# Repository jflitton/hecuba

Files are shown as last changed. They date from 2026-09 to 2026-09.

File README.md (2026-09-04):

# Hecuba

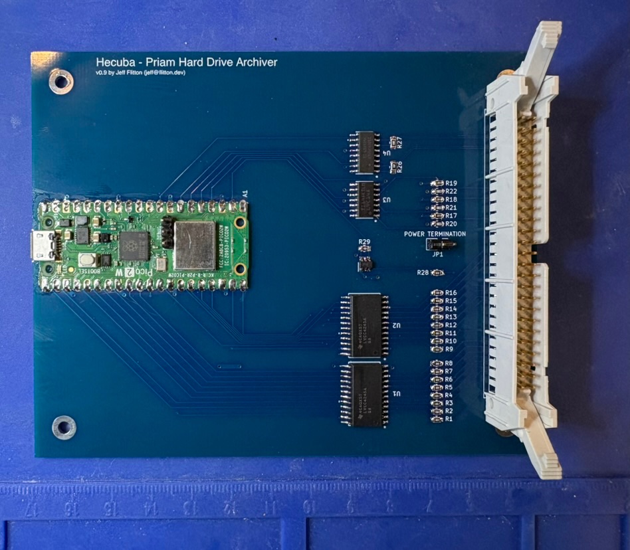
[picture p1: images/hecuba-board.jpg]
Hecuba interface board, rev 0.9, with the Pico 2 W fitted and the 50-pin drive connector on the right


A read-only imager for Priam DISKOS 8-inch Winchester drives, talking to the
drive over its native PRIAM 50-pin interface. Three parts: a small interface
board, firmware for the Raspberry Pi Pico 2 W that plugs into it, and host-side
Python tools that image the drive, recover damaged sectors offline, and walk
the recovered filesystem.

It was built to recover a Priam 3450 pulled from an Intel Multibus development
system (iSBC 215 controller, iRMX-86), and has imaged that drive in full. The
name: Hecuba was queen of Troy and wife of Priam.

## For data preservationists

If you have a Priam DISKOS 8-inch drive (a 3450, or likely a 7050) whose
contents you want to archive, email <jeff@flitton.dev>. I have a handful of
assembled Hecuba boards and can send you one. I am also glad to help with the
imaging and recovery, and to answer questions about the drive or its interface.

## Layout

| Directory | Contents | README |
|---|---|---|
| `hardware/` | KiCad project for the interface board: schematic, layout, BOM, measured termination values, 50-pin pinout | [hardware/README.md](hardware/README.md) |
| `firmware/` | Pico 2 W firmware: PRIAM register bus, PIO/DMA track capture, USB serial console | [firmware/README.md](firmware/README.md) |
| `software/` | Host tools: whole-drive imaging, three offline recovery passes, iSBC 215 sector decoder, iRMX-86 filesystem walker, defect map | [software/README.md](software/README.md) |

## Why it exists

These drives have a unique interface that resembles SASI at first glance but
is distinctly different.

- The heads move only on the drive's own command. There is no STEP line; a seek
  is a register write over the ribbon. The drive must be powered, spun up, and
  answering before it will read anything.
- The interface is recovered NRZ data plus clock on RS-422 pairs at 6.4 Mbit/s,
  not raw flux. A flux imager has nothing to read.

Acquisition and decoding are kept separate: capture each track once, cleanly,
then decode and repair offline, minimizing drive wear.

## Workflow

1. Build the board (`hardware/`). Rev 0.9A is fabricated and assembled.
2. Build and flash the firmware (`firmware/`), then bring the drive up from the
   USB serial console: `up`, `id`, `pins`, `stair`.
3. Image the drive with `software/sweep.py`, which drives that console and
   writes per-track sector images plus every raw capture.
4. Recover remaining sectors offline with `vote_repair.py`, `rescue.py`, and
   `deep_rescue.py`.
5. Walk the volume with `irmx_fs.py`, and attribute unrecovered sectors with
   `defect_map.py`.

## Read-only

The board has no copper on the write lines, and the firmware has no code path
that asserts WRITE GATE. Writing to a disk would require modifying the board.

## Scope

The sector decoder and filesystem walker target what this drive held: the Intel
iSBC 215 512-byte sector format and iRMX-86 named volumes. The board and
firmware are format-agnostic and capture raw bits from any drive with the PRIAM
interface. Termination values in `hardware/` were measured on one drive;
measure yours before populating.

Only the DISKOS 3450 has been tested. The DISKOS 7050 shares the same
interface, electrical spec, and service manual, so the board and firmware
should work on it as well, unconfirmed. The 7050 has 1049 cylinders to the
3450's 525, and that count is hardcoded in `firmware/include/priam_proto.h`
and `software/sweep.py`; the `id` command also expects the 3450's ID code.

No disk contents are part of this repository.

## License

The firmware and software are released under the MIT License, see
[LICENSE](LICENSE). The hardware design under `hardware/` is released under the
CERN Open Hardware Licence Version 2, Permissive (CERN-OHL-P-2.0), see
[hardware/LICENSE](hardware/LICENSE).

Both licenses allow commercial use, and both require that the copyright notice
and license text stay with copies and derived works. Both disclaim all
warranties: the software, the firmware, the design files, and any board built
from them are provided as is, and the risk of building and using them is
yours. Vendor symbol and footprint files under `hardware/lib/` are Texas
Instruments' and are not covered by either license.

## Reference documents

- [Priam 8-inch Winchester maintenance manual, July 1982](https://bitsavers.org/pdf/priam/Priam8_Maint_Jul82.pdf),
  and its [drawings volume](https://bitsavers.org/pdf/priam/Priam8_Maint_Drawings_Jul82.pdf)
  (schematics; an [800 dpi scan](https://bitsavers.org/pdf/priam/Priam8_Maint_Drawings_800dpi_Jul82.pdf) is also there)
- [Intel iSBC 215 Winchester Disk Controller Hardware Reference Manual,
  121593-002, September 1981](https://bitsavers.org/pdf/intel/iSBC/121593-002_iSBC_215_Winchester_Disk_Controller_Hardware_Reference_Manual_Sep1981.pdf)
- David Gesswein's excellent [mfm](https://www.pdp8online.com/mfm/) project, which documents the iSBC 215 sector format

## Author

Jeff Flitton, <jeff@flitton.dev>

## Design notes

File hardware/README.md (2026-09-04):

# Hecuba hardware

KiCad project for the Hecuba interface board. It sits between a Priam DISKOS
8-inch Winchester drive's native 50-pin interface and a Raspberry Pi Pico 2 W
(ref `A1`), which runs the firmware in `../firmware`. Rev 0.9A is fabricated,
assembled, and has imaged a full Priam 3450. Read-only by design.

## Why a custom board

The Priam 3450 (about 35 MB, 3,600 RPM, 5 heads, 525 cylinders) fits none of
the usual readers.

- No STEP line. Heads are positioned by a closed-loop voice-coil servo under an
  on-board 8035. A seek is a register write plus a Seek command, and the drive
  must be powered, spun up, and taking commands before it returns a bit.
- Not a flux interface. The drive does its own data separation and outputs
  recovered NRZ data plus clock on RS-422 pairs at 6.4 Mbit/s.
- The sector format belongs to the controller that wrote the disk (an Intel
  iSBC 215 here), not to the drive. Decoding happens offline in `../software`.
- Not SASI, despite the 50-pin ribbon and 8-bit active-low bus. PRIAM has no
  REQ/ACK handshake and carries read data on separate differential pairs.

## Building one

| | |
|---|---|
| Board | 2 layers, 125 x 104 mm, 1.6 mm. Signals on top; bottom is a ground pour with +5 V and +3.3 V routed through it as 1 mm paths |
| Tracks and vias | 0.2 mm signal, 1.0 mm power. Vias 0.6 mm / 0.3 mm hole (1.0 / 0.6 on power) |
| Smallest features | 0.2 mm track, 0.3 mm hole, 0.5 mm copper to edge |
| Packages | SOIC and SOT-23-6 ICs, 0805 passives. Hand-solderable in about an hour |
| Mounting | Four 3 mm plated holes, grounded |
| Parts list | `bom/bom.csv`, with a column for parts deliberately left unpopulated |
| Placement guide | `bom/ibom.html`, interactive; click a part to see where it goes |

All ICs are current-production TI parts as of 2026. Gerbers are plotted from
KiCad when needed and are not committed.

Routing rules for a respin:

- Only READ DATA and READ/REF CLOCK need care. Route each as a tight parallel
  pair over unbroken ground, and keep the two pairs apart. No impedance control
  and no length matching (the skew budget at 6.4 Mbit/s is about 170 mm).
- Everything else is slow. Keep the 8 data-bus lines grouped.
- Damping resistors at the source, termination at the receiver, and each
  100 nF capacitor hard against its power pin with its own ground via.

## Parts

| Ref | Part | Function | Datasheet |
|---|---|---|---|
| A1 | Pico 2 W (RP2350) | Controller. Powers the board over USB | [raspberrypi.com](https://datasheets.raspberrypi.com/picow/pico-2-w-datasheet.pdf) |
| U1 | SN74LVC4245A | 8-bit data bus, bidirectional. Direction set by the Pico (GP8) | [ti.com](https://www.ti.com/lit/ds/symlink/sn74lvc4245a.pdf) |
| U2 | SN74LVC4245A | Outbound control lines: address, strobes, head select, read gate. Direction strapped | [ti.com](https://www.ti.com/lit/ds/symlink/sn74lvc4245a.pdf) |
| U3 | SN74LVC14A | Schmitt-trigger inverters on INDEX, READY, SECTOR MARK | [ti.com](https://www.ti.com/lit/ds/symlink/sn74lvc14a.pdf) |
| U4 | AM26LV32E | RS-422 receivers for READ DATA and READ/REF CLOCK. Receive only | [ti.com](https://www.ti.com/lit/ds/symlink/am26lv32e.pdf) |
| U5 | SN74LVC1T45 | -RESET driver. Direction strapped | [ti.com](https://www.ti.com/lit/ds/symlink/sn74lvc1t45.pdf) |
| J1 | 2x25 IDC header | 50-pin ribbon to the drive | |

## Termination

Measured on one drive. Measure yours before populating. The manual's generic
values assume the controller terminates everything; this drive terminates most
of the bus internally. Values were measured at the connector with the drive
unpowered and the ribbon off.

| Part | Value | Fitted | Reason |
|---|---|---|---|
| R1-R16, R28 | 0 ohm | yes | Series damping on outbound lines. The drive terminates this bus at about 179 ohm; even 33 ohm in series lifts a logic low to about 0.72 V against a 0.8 V threshold. Fit 10 ohm or less only if a scope shows overshoot |
| R17 / R20 | 220 / 330 ohm | yes | INDEX pull-up and pull-down. INDEX measured open at the drive. Settles near 3.0 V released |
| R18-R19 / R21-R22 | 220 / 330 ohm | no | READY and SECTOR MARK are pulled up inside the drive (130 / 175 ohm measured). Fit only if J1 pin 28 is left unpowered |
| R26 | 1 k | yes | Bias across the CLOCK pair, which measured 95 ohm. 100 ohm here would load the pair to 49 ohm |
| R27 | 100 ohm | yes | Termination across the DATA pair, which measured 252 ohm |
| R29 | 10 k | yes | Pull-up on GP17 (-RESET). Holds reset deasserted through boot |
| C1-C8 | 100 nF | yes | Decoupling, one per power pin |
| C9 / C10 | 10 uF | yes | Bulk on each rail at the Pico's power pins |
| JP1 | 2-pin header | shunt open | +5 V to J1 pin 28 (terminator power). Not needed on the drive tested |

## 50-pin connector (J1)

| Signal | Pin | Direction | Connects to |
|---|---|---|---|
| DBUS 0-7 | 2-9 | both | U1 via R1-R8 |
| -READ GATE | 11 | to drive | U2 via R9 |
| -RESET | 13 | to drive | U5 via R28 |
| -WRITE GATE | 15 | to drive | not connected |
| -RD / -WR | 17 / 18 | to drive | U2 via R10 / R11 |
| +AD 1 / +AD 0 | 19 / 20 | to drive | U2 via R12 / R13 |
| -DRIVE SELECT 1 | 22 | to drive | ground (always selected) |
| -DRIVE SELECT 2-4 | 23-25 | to drive | not connected |
| +5 V to terminator | 28 | power | JP1 (open) |
| -HEAD SELECT 4 / 2 / 1 | 29 / 30 / 31 | to drive | U2 via R14 / R15 / R16 |
| -INDEX | 33 | from drive | U3, with R17 / R20 |
| -READY | 35 | from drive | U3 |
| -SECTOR MARK | 37 | from drive | U3 |
| WRITE DATA pair | 39 / 40 | to drive | not connected |
| WRITE CLOCK pair | 42 / 43 | to drive | not connected |
| READ/REF CLOCK pair | 45 / 46 | from drive | U4, R26 across |
| READ DATA pair | 48 / 49 | from drive | U4, R27 across |

Ground pins 1, 10, 12, 14, 16, 21, 26, 27, 32, 34, 36, 38, 41, 44, 47, 50
connect to the ground plane.

## Power

- Drive rails (+24 V, +5 V, -5 V, -12 V, about 100 W total) come from a bench
  supply into the drive's own connector. The board neither carries nor senses
  them. Current-limit and watch +24 V at power-up; it runs the spindle and the
  voice coil.
- Board rails come from the Pico's USB. VBUS (pin 40) feeds the drive-facing
  side of the translators and the status pull-ups. The Pico's 3.3 V regulator
  (pin 36) feeds the Pico-facing side.
- Board draw is about 250 mA idle and 400 to 600 mA peak (the radio spikes on
  transmit). Use a 1.5 A supply or powered hub.

Power the Pico first, then the drive, and do not replug USB while the drive is
powered. Until firmware init runs, the Pico's pins are inputs with pull-downs,
which asserts every active-low control line through U2. Only -RESET is
protected in hardware (R29).

## Noteworthy facts

- **Write lines have no copper.** WRITE GATE, WRITE DATA, and WRITE CLOCK
  appear on the connector symbol only. No trace, no resistor. Writing would
  require adding wires to the board. The drive's own Write Enable switch is
  also off, and its internal terminator holds WRITE GATE deasserted.
- **The drive is 5 V TTL; the RP2350 is 3.3 V and not 5 V tolerant.** Every
  signal crosses a translator. Net names carry the level: `DBUS0` on the drive
  side, `DBUS0_3V3` on the Pico side.
- **Status lines invert.** U3 inverts, so INDEX, READY, and SECTOR MARK read
  active-high at the Pico while every other PRIAM signal is active-low. The
  schematic writes active-low nets as `~{NAME}`; the drive manual uses a
  leading minus. The full per-line chain is in
  `../firmware/include/board_pins.h`.
- **U3 is a Schmitt trigger on purpose.** The drive's status outputs are
  open-collector 75462s with slow RC rising edges. Hysteresis turns each into
  one clean transition. The drive's own end uses 74LS14s for the same reason.
- **U4 is the E variant on purpose.** AM26LV32E adds hysteresis and an
  open-input fail-safe, so the read pairs hold a defined level before READ GATE
  asserts and before the drive's clock recovery locks.
- **R29 is load-bearing.** U5 has no output enable and follows GP17 from
  power-on, and the RP2350 boots GP17 as an input with a pull-down. Without
  R29 every power-up would reset the drive.
- **DRIVE SELECT 1 is tied to ground.** One drive, permanently selected, no
  chip-select GPIO. The data bus still only drives back during a read strobe.
- **Unused U3 and U4 inputs are tied off.** Floating Schmitt or differential
  inputs oscillate.
- **R26 and R27 differ by 10x** for two pairs on the same connector. Only
  measurement finds that.

## Files

| Path | Contents |
|---|---|
| `hecuba.kicad_pro` | Project settings, net classes, design rules |
| `hecuba.kicad_sch` | Schematic, one sheet |
| `hecuba.kicad_pcb` | Board layout |
| `hecuba.kicad_prl` | KiCad UI state |
| `hecuba.kicad_sym` | Five project symbols. `PRIAM_50` is the drive connector with real PRIAM signal names |
| `footprints.pretty/` | Footprints for the four ICs, registered by `fp-lib-table` so the project opens standalone |
| `fp-lib-table` | Points KiCad at the folder above |
| `lib/<PART>/` | Vendor symbol and footprint downloads per chip, untouched. Datasheets are linked from the parts table, not stored here |
| `bom/bom.csv` | Parts list with populate / do-not-populate column |
| `bom/ibom.html` | Interactive BOM |

`.gitignore` covers KiCad backups and netlist output.

## License

CERN Open Hardware Licence Version 2, Permissive (CERN-OHL-P-2.0). The full
text is in [LICENSE](LICENSE). Keep the copyright and license notices with any
copy or derivative of the design files, and on boards where practicable (the
silkscreen already carries the author line). The design is provided as is, with
no warranty, and the risk of building and using a board from it is yours.

Files under `lib/<PART>/` are Texas Instruments vendor downloads under TI's own
terms and are not covered by this license.

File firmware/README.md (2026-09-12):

# Hecuba firmware

Firmware for the Raspberry Pi Pico 2 W (RP2350) on the Hecuba board (ref `A1` in
`../hardware`). It drives a Priam DISKOS 8-inch drive over its native 50-pin
interface and captures whole-track NRZ bit streams for offload over USB serial.

Read-only. No code path asserts -WRITE GATE or drives WRITE DATA / WRITE CLOCK,
and the board has no copper on those pins.

## Build and flash

VS Code: install the official Raspberry Pi Pico extension and open `firmware/`
as the project root (the extension only handles single-folder workspaces). It
supplies the SDK, CMake, Ninja, the ARM toolchain, picotool, and OpenOCD.

Command line:

```bash
export PICO_SDK_PATH=/path/to/pico-sdk          # 2.1 or newer
cmake -B build -G Ninja \
  -DPICO_TOOLCHAIN_PATH=/path/to/arm-gnu-toolchain \
  -DCMAKE_PREFIX_PATH="$(brew --prefix)"        # locates picotool
cmake --build build                             # build/hecuba.uf2
```

Flash: hold BOOTSEL while plugging in USB, then drag `build/hecuba.uf2` onto the
`RP2350` drive or run `picotool load -fx build/hecuba.uf2`.

- Pico SDK 2.1 is the minimum. Older SDKs do not know the RP2350.
- Use Arm's own `arm-none-eabi` toolchain. Homebrew's formula lacks newlib and
  fails at link with `cannot read spec file 'nosys.specs'`.

## Console

All control and diagnostics go over USB serial at 115200. There is no debug
UART (GP0 and GP1 are data bus lines). The banner reprints on every connect.
Type `help`.

```bash
screen /dev/tty.usbmodem* 115200
```

| Command | Action |
|---|---|
| `status` | Read and decode the Status register |
| `up [secs]` | Sequence Up: spin up, restore to cylinder 0, wait for READY. About 30 s; timeout default 35 |
| `down` | Sequence Down: park heads, brake spindle |
| `seek <cyl>` | Seek to cylinder 0 to 524 |
| `head <0-4>` | Select a data head |
| `gate on\|off` | Assert or deassert -READ GATE |
| `id` | Read Drive ID. A 3450 returns `0x04` |
| `capture <cyl> <head>` | Seek, select head, open gate, settle, capture one INDEX-aligned track |
| `capraw [head]` | Capture with no seek and no status checks (bench and loopback) |
| `dump [n]` | Hexdump the first n words of the last capture (default 16) |
| `dumpb64 [n]` | Base64 the capture buffer to the host |
| `pins` | GPIO levels plus rising-edge counts over 100 ms |
| `reg r <ad>` | Raw register read (ad = 0, 1, 2) |
| `reg w <ad> <hex>` | Raw register write |
| `stair` | Seek staircase 0, 1, 0, 2, ... 524 with address readback at every step. About 1,050 seeks, a few minutes, any key aborts |
| `gating [off\|mark\|both] [drop_us] [data_off_us] [data_drop_us]` | Per-field -READ GATE pulses during capture. See below |
| `reset` | Pulse -RESET for 1 ms. Not part of any normal sequence |

Typical session:

```
> id
drive id = 0x04 (expect 0x04 for 3450)
> up
sequence up: OK  status 0x0B [READY SEEKCMP CYL0 ]
> pins
levels : INDEX=0 READY=1 SECTOR=0 CLK=1 DATA=0
edges/100ms: INDEX=6 SECTOR=138 (expect 6 / 138 spinning) CLK~... DATA~... (aliased; nonzero = alive)
> capture 0 0
(capture engine started on core1)
capture cyl 0 head 0: OK: 3780 words (15120 bytes)
> dumpb64
-----BEGIN CAPTURE b64 (3780 words, LE, first bit = LSB)-----
...
> down
sequence down: OK  status 0x00 []
```

`../software/sweep.py` drives this console to image a whole drive.

## Bench procedure

1. Power the Pico over USB first and let it boot. Do not replug USB while the
   drive is powered. Until `priam_bus_init()` runs, the Pico's pins are inputs
   with pull-downs, which asserts every active-low control line at once. Only
   -RESET is protected in hardware (R29).
2. Bring up the drive rails.
3. `up`, then `id`, then `pins`. A spinning drive shows about 6 INDEX and 138
   SECTOR MARK edges per 100 ms with READY=1. Clock and data counts are
   aliased; only nonzero matters.
4. Run `stair` before a long imaging run. It exercises the servo over its full
   travel and confirms the cylinder bit packing. It stops on the first failure.
5. Capture. `down` when finished.

Capture failures:

| Situation | Timeout | Message |
|---|---|---|
| No INDEX pulse | 60 ms | `FAIL: no INDEX edge, or clock never ran` |
| Clock stops mid-track | 250 ms | `PARTIAL: n/3780 words` |

Both point at `pins`. Zero clock edges with the drive spinning and the gate
open means the read channel is not reaching the board.

## Capture format

Raw sampled bits, no decoding. One capture is 3,780 32-bit words (15,120
bytes), about 12.5% more than one revolution (3,360 words, 13,440 bytes,
16.7 ms at 3,600 RPM). INDEX alignment is done in software, so the margin
guarantees a full INDEX-to-INDEX window with overlap rather than a gap.

- The first bit sampled is bit 0 of word 0, the 32nd is bit 31 (the PIO shifts
  right).
- `dumpb64` emits each word little-endian. The first bit off the platter is the
  LSB of the first byte received.

`../software/decode_scout.py` decodes this stream (iSBC 215 format, 512 B
sectors).

## Per-field gate re-sync

-READ GATE is pulsed off and on per field during a capture, following the
original controllers:

- PRIAM OEM/Service Manual 308000-0, Figure 3-40 and Table 3-15: READ GATE is
  asserted in the zero gap after SECTOR MARK and dropped before the next write
  splice. READ DATA is invalid for 9 µs after each assertion (PLO sync).
- iSBC 215 Hardware Reference Manual 121593-002, paragraphs 4-29 and 4-30:
  RD GATE is reset by END TIME at the end of the ID field's ECC and "again
  raised to search for the sync byte of the data field".

With the gate held across a write splice the separator's output for the
following field is unreliable and the field fails ECC.

Timing for the iSBC 215 sector format (1.24 µs per byte), from the SECTOR MARK
leading edge: ID sync byte about 22 µs, ID field end about 33 µs, data-field
write splice about 44 µs (the 215 writes ID fields and data fields in separate
format passes, so every sector has one), data sync byte about 68 µs.

```
gating                   show the setting (default: both 3 37 11)
gating both 3 37 11      gate off 3 µs at each SECTOR MARK, and off from 37 to
                         48 µs after it (spans the splice, ~18 µs of zeros left
                         for the resync)
gating mark [drop_us]    mark pulse only
gating off               gate held for the whole revolution
```

Capture lines report `[gating both, N drops, mark0 +NNus]`: N is the number of
gate pulses over the INDEX wait plus the track; `mark0` is the INDEX to first
SECTOR MARK time (spec 44.6 ± 1.4 µs).

## Noteworthy facts

- **Capture is PIO plus DMA, not CPU.** `src/capture.pio` is three
  instructions: wait for the drive's clock high, wait for it low, shift in one
  READ DATA bit. No local clock or sample rate exists; the drive's recovered
  clock paces everything. DMA drains the FIFO into RAM. A CPU breakpoint does
  not stop a capture.
- **Sample on the falling clock edge.** READ DATA changes shortly after the
  rising edge of READ/REF CLOCK, so a sample there lands on the transition.
  The falling edge is mid-cell.
- **Gate per field.** A capture with the gate held for the whole revolution
  loses the field after each write splice. See "Per-field gate re-sync".
- **Two cores by role.** core0 runs the register bus and USB console. core1
  runs only the capture engine and starts on the first capture, so a PIO or
  DMA problem cannot take the console down. The 1 Hz LED heartbeat stops during
  a capture because core0 blocks on core1.
- **pio1, not pio0.** The Pico 2 W LED hangs off the CYW43 radio, whose driver
  claims a pio0 state machine at startup. The wireless stack is linked only for
  the LED. There is no networking.
- **Status bits are invalid while BUSY is set.** SEEK COMPLETE, SEEK FAULT, and
  COMMAND REJECT flutter during spin-up. Wait for BUSY to clear before judging
  them. An early version aborted a good `up` with status `0xD0` for this reason.
- **DRIVE FAULT is never retried.** The firmware reports it and stops.
- **`down` can report FAIL with status `0x50` after a successful park.** The
  spindle brake outlasts the status timeout, leaving BUSY set.
- **`reset` on a sequenced-up drive restores it to cylinder 0** and takes
  about 450 ms to come back READY. DRIVE FAULT appears at once and the drive
  clears it itself; a fault that persists means the restore failed. A pulse
  of a few microseconds is enough, despite the manual's 100 ms figure.
- **Init order.** `priam_bus_init()` is the first call in `main()`. It writes
  each pin's idle level before switching it to output, because the SDK zeroes
  the output latch on init. The reverse order drives every active-low line low
  for a few microseconds.
- **Polarity.** Control outputs pass through a non-inverting buffer, so assert
  means drive the GPIO low. The three status inputs pass through an inverting
  Schmitt trigger and read active-high at the Pico. `include/board_pins.h`
  documents the chain for every line.
- **Geometry is the 3450's.** `include/priam_proto.h` fixes 525 cylinders and
  5 heads, and `seek`, `stair`, and `capture` reject cylinders above 524. A
  DISKOS 7050 (1049 cylinders, same interface) should work with those constants
  changed. Untested.

## Register interface

Three registers selected by AD0/AD1. Read and write address different
registers.

| Address | Write | Read |
|---|---|---|
| 0 | Command | Status |
| 1 | Target Address upper | Current Address upper |
| 2 | Target Address lower | Current Address lower |

Commands: `0x01` Sequence Up, `0x02` Sequence Down, `0x03` Restore, `0x04`
Seek, `0x05` Fault Reset, `0x10` Read Drive ID. A seek writes the cylinder into
registers 1 and 2, writes `0x04` to register 0, then polls register 0 until
BUSY clears.

Status bits: READY, SEEK COMPLETE, SEEK FAULT, CYLINDER ZERO, BUSY, DRIVE
FAULT, WRITE PROTECT, COMMAND REJECT. The console decodes them (`0x0B` prints
`[READY SEEKCMP CYL0 ]`).

Bus timing. There is no handshake beyond the strobes; every value is padded
above the manual's minimum using the SDK's minimum-cycle busy-wait.

| Parameter | Manual minimum | Used |
|---|---|---|
| Address setup before strobe | 60 ns | 80 ns |
| Data setup before -WR release | 60 ns | 80 ns |
| -WR low | 100 ns | 150 ns |
| -RD low | 100 ns | 150 ns |
| Data valid after -RD | 60 ns | 80 ns |
| Gap between strobes | 200 ns | 250 ns |

## Pin map

`include/board_pins.h` is authoritative.

| GPIO | Signal | Dir | Via | Notes |
|---|---|---|---|---|
| GP0-7 | DBUS 0-7 | both | U1 '4245 | Direction from GP8: 0 = Pico drives, 1 = drive drives |
| GP8 | DBUS direction | out | | Controls U1 |
| GP9, GP10 | AD0, AD1 | out | U2 '4245 | Register select, plain logic levels |
| GP11, GP12 | -RD, -WR | out | U2 | Strobes, assert = low |
| GP13-15 | -HEAD SELECT 1, 2, 4 | out | U2 | Assert = low. HS1 is bit 0, HS4 is bit 2 |
| GP16 | -READ GATE | out | U2 | Assert = low |
| GP17 | -RESET | out | U5 1T45 | Assert = low. R29 holds it deasserted through boot |
| GP18 | -INDEX | in | U3 '14, inverting | Reads active-high at the Pico |
| GP19 | -READY | in | U3, inverting | Reads active-high |
| GP20 | -SECTOR MARK | in | U3, inverting | Reads active-high |
| GP21 | READ/REF CLOCK | in | U4 RS-422 | The PIO `wait gpio` pin |
| GP22 | READ DATA | in | U4 RS-422 | The PIO `in pins` pin |

No drive-select GPIO. DRIVE SELECT 1 is tied asserted on the board.

## Debugging

No probe is needed. The drive was imaged using BOOTSEL flashing and the serial
console.

`.vscode/launch.json` is set up for a CMSIS-DAP probe (the Raspberry Pi Debug
Probe, or a Pico running `debugprobe_on_pico`: GP2 to SWCLK, GP3 to SWDIO,
ground to ground on the 3-pin debug header) with RTT logging. Enable RTT with
`pico_enable_stdio_rtt(hecuba 1)` in `CMakeLists.txt`; it keeps `printf` off
USB and away from the capture core. PIO and DMA keep running under a
breakpoint, so inspect captures with `dump` afterwards.

`c_cpp_properties.json` points IntelliSense at `build/compile_commands.json`,
which exists after the first configure. `settings.json` disables CMake Tools so
it does not fight the Pico extension.

## Files

| Path | Contents |
|---|---|
| `include/board_pins.h` | GPIO map with polarity and translator chain per line |
| `include/priam_proto.h` | Register addresses, command codes, Status bits, geometry, cylinder packing |
| `src/main.c` | Startup: park drive-facing lines, bring up USB and LED, run the console loop |
| `src/priam_bus.c`, `.h` | Register bus: strobes and timing through Sequence Up, Seek, head select |
| `src/capture.pio` | The three-instruction sampler |
| `src/capture.c`, `.h` | Capture engine on core1: PIO and DMA setup, INDEX alignment |
| `src/host_cli.c`, `.h` | The console |
| `CMakeLists.txt` | Selects the Pico 2 W, assembles the PIO program, links PIO, DMA, multicore, USB stdio |
| `pico_sdk_import.cmake` | Stock SDK locator, unmodified |
| `.vscode/` | Editor and debugger configuration |
| `build/` | Build output including `hecuba.uf2`. Generated, not committed |

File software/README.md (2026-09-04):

# Hecuba software

Host-side tools for the Hecuba board: image a Priam drive over the firmware's USB
console, recover more sectors offline from the saved raw captures, and walk the
iRMX-86 filesystem on the assembled image. Python 3. Only `sweep.py` needs an extra
package (pyserial).

Scripts in pipeline order:

## sweep.py

Whole-drive imaging. Drives the firmware console, captures each track, decodes it
inline, and re-reads until every sector validates or reads stop adding sectors.
Writes `image/manifest.json`, one `image/tracks/cylCCC_hN.bin` per track, and every
distinct raw capture under `image/raw/`. Resumable; reruns skip completed tracks.

    python3 sweep.py --probe                     # connect + status, no motion
    python3 sweep.py                             # image everything
    python3 sweep.py --cyls 0:100 --heads 1,2,3,4
    python3 sweep.py --revisit                   # retry previously-failed tracks

## vote_repair.py

Offline. For every sector still marked `failed`, extracts that sector's data field
from every saved raw capture, drops outlier reads, majority-votes per bit, and
ECC-checks the result. Writes winners back into `tracks/` and the manifest as `voted`.

    python3 vote_repair.py [--image image] [--min-reads 3] [--dry-run]

## rescue.py

Offline. Recovers sectors whose header is dead but whose data field is intact.
Builds a slot-to-sector map from header positions across all reads, then scans each
slot for an ECC-valid data field. Marks results `position`.

    python3 rescue.py [--image image] [--dry-run] [--jobs 8] [--cyls A:B]

## deep_rescue.py

Offline, last resort. Sliding ECC scan over the slot window, aligned per-bit vote
across reads, and single bit-slip repair. Marks results `deep`.

    python3 deep_rescue.py [--image image] [--dry-run] [--jobs 8]

## irmx_fs.py

Walks an iRMX-86 named volume: label, fnode table, directory tree. Reports per-file
intactness against a missing-sector list and writes the full listing to a file.

    python3 irmx_fs.py [--img volume.img] [--missing volume.missing.json] [--tree-out filetree.txt]

## defect_map.py

Decodes the Priam 3450 reserved area (cylinders 513 to 524) and the format-time
bad-track table on cylinder 523, then splits unrecovered sectors into factory
defects and real storage-era loss, attributed to owning files.

    python3 defect_map.py [--img volume.img] [--missing volume.missing.json] [--json defects.json]

## decode_scout.py

The iSBC 215 sector decoder every other script imports: header and data field
search at any bit alignment, CRC-32 ECC check, 4-bit burst correction. Also runs
standalone on a screen log or raw track files.

    python3 decode_scout.py <screenlog|track.bin>... [--out track.bin] [--peek]

## Notes

- `sweep.py`, `vote_repair.py`, `rescue.py`, and `deep_rescue.py` all write
  `image/manifest.json` and `image/tracks/`. Never run two of them at once.
- Sector states in the manifest: `valid`, `corrected` (burst-corrected on read),
  `voted`, `position`, `deep` (the three offline passes), `failed`, `no-header`,
  `erased-ff`.
- Images, raw captures, and anything recovered from a particular drive are not
  part of this repository.

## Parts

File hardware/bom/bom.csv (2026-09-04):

Ref | Qty | Value | Description | Manufacturer | MPN | Footprint | Populate | Notes
A1 | 1 | Pico 2 W | RP2350 controller module | Raspberry Pi | Pico 2 W (SC1634 - verify) | Pico 2 W module | Yes | Controller core (CORE-1); 3.3V GPIO not 5V tolerant
U1 | 1 | SN74LVC4245A | Octal 5V<->3.3V translating transceiver | Texas Instruments | SN74LVC4245ADWR | SOIC-24W | Yes | DBUS bidirectional; VCCA=5V VCCB=3.3V; DIR from GPIO
U2 | 1 | SN74LVC4245A | Octal 5V<->3.3V translating transceiver | Texas Instruments | SN74LVC4245ADWR | SOIC-24W | Yes | Control outputs; DIR strapped B->A (pin2=GND)
U3 | 1 | SN74LVC14A | Hex Schmitt-trigger inverter | Texas Instruments | SN74LVC14ADR | SOIC-14 | Yes | Status inputs (inverting -> active-high at core)
U4 | 1 | AM26LV32E | Quad RS-422 line receiver 3.3V | Texas Instruments | AM26LV32EIDR | SOIC-16 | Yes | READ DATA + READ/REF CLOCK; receiver-only
U5 | 1 | SN74LVC1T45 | Single-bit 5V<->3.3V translator | Texas Instruments | SN74LVC1T45DBVR | SOT-23-6 | Yes | Hardware -RESET driver (drive 8035 reset); VCCA=5V VCCB=3.3V; DIR(5)->GND (B->A)
J1 | 1 | 50-pin IDC | PRIAM 50-pin ribbon header 2x25 | Generic | TBD | IDC 2x25 2.54mm | Yes | To drive 50-pin connector
R1-R16 | 16 | 0R | Series source-damping (controller->drive) | Generic | TBD | 0805 | Yes | 0R default - keeping out an of an abundance of caution; <=10R if overshoot
R17 | 1 | 220R | Status pull-up to +5V (INDEX) | Generic | TBD | 0805 | Yes | INDEX terminator (with R20); drive open on INDEX (measured) so we terminate
R20 | 1 | 330R | Status pull-down to GND (INDEX) | Generic | TBD | 0805 | Yes | INDEX terminator (with R17)
R18-R19 | 2 | 220R | Status pull-up to +5V (READY/SECTOR) | Generic | TBD | 0805 | DNP | Drive pulls these up at term rail (measured) - populate only if J1 pin28 left unpowered
R21-R22 | 2 | 330R | Status pull-down to GND (READY/SECTOR) | Generic | TBD | 0805 | DNP | Pairs with R18-R19
R26 | 1 | 1k | RS-422 READ/REF CLOCK pair termination | Generic | TBD | 0805 | Yes | Drive terminates CLOCK pair (~95R measured) - light 1k bias; do NOT use 100R (->49R)
R27 | 1 | 100R | RS-422 READ DATA pair termination | Generic | TBD | 0805 | Yes | Drive weakly terminates DATA pair (252R measured) - supply ~100R
R28 | 1 | 0R | Series source-damping (-RESET to drive) | Generic | TBD | 0805 | Yes | U5 A-output (pin3) -> J1 pin13; 0R default (<=10R if overshoot)
R29 | 1 | 10k | GP17 pull-up to +3V3 | Generic | TBD | 0805 | Yes | Keeps -RESET deasserted through boot (U5 has no OE; RP2350 GP17 resets to input+pull-down)
C1-C8 | 8 | 100nF | X7R decoupling per Vcc pin | Kemet | C0805C104J5RACTU | 0805 | Yes | U1 x2; U2 x2; U3 x1; U4 x1; U5 x2
C9-C10 | 2 | 10uF | X7R bulk decoupling +5V and +3.3V | Murata | GRM21BZ71E106KE15K | 0805 | Yes
JP1 | 1 | 2-pin header | Terminator power select: +5V to J1 pin 28 | Generic | TBD | Header 1x2 2.54mm | Yes | Header populated; shunt OPEN by default - install only if drive needs host-supplied term power (verify; adds ~100mA to +5V)

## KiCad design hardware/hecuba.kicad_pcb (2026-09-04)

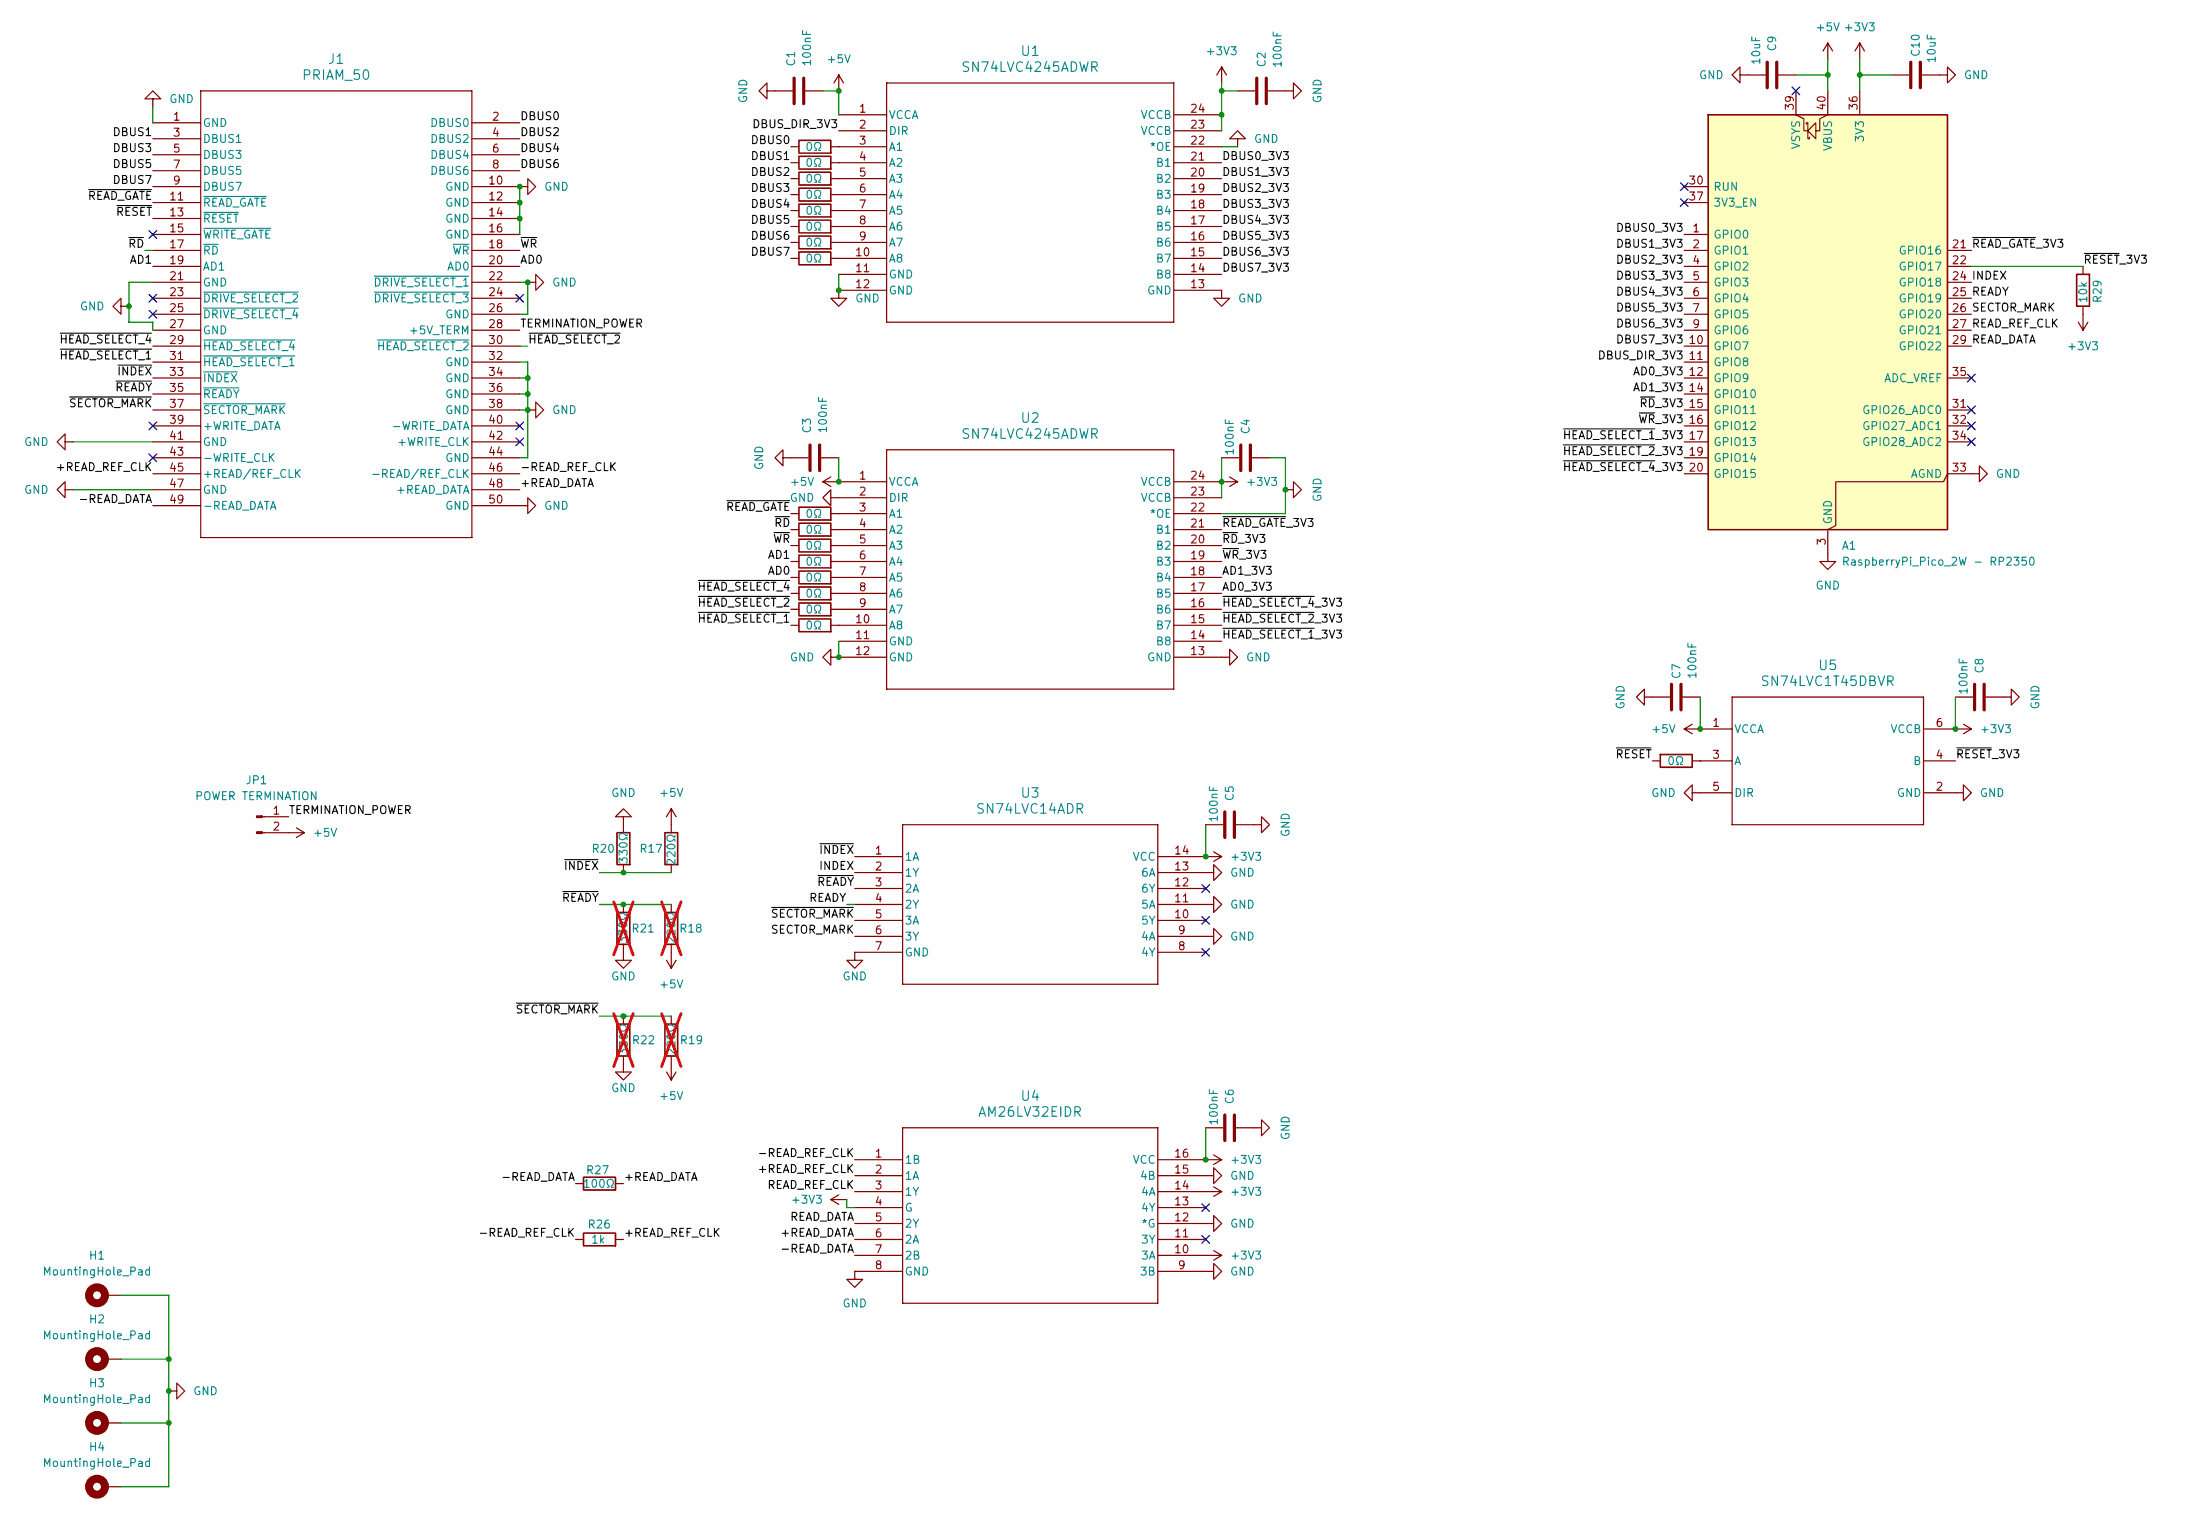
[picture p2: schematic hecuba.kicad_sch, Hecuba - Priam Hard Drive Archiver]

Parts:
A1: RaspberryPi_Pico_2W - RP2350; RaspberryPi_Pico_W_SMD_HandSolder
C1, C2, C3, C4, C5, C6, C7, C8: 100nF; C_0805_2012Metric_Pad1.18x1.45mm_HandSolder
C9, C10: 10uF; C_0805_2012Metric_Pad1.18x1.45mm_HandSolder
H1, H2, H3, H4: MountingHole_Pad; MountingHole_3mm_Pad
J1: PRIAM_50; IDC-Header_2x25_P2.54mm_Vertical
JP1: POWER TERMINATION; PinHeader_1x02_P2.54mm_Vertical
R1, R2, R3, R4, R5, R6, R7, R8, R9, R10, R11, R12, R13, R14, R15, R16, R28: 0Ω; R_0805_2012Metric_Pad1.20x1.40mm_HandSolder
R17: 220Ω; R_0805_2012Metric_Pad1.20x1.40mm_HandSolder
R18, R19: 220Ω; R_0805_2012Metric_Pad1.20x1.40mm_HandSolder; not fitted
R20: 330Ω; R_0805_2012Metric_Pad1.20x1.40mm_HandSolder
R21, R22: 330Ω; R_0805_2012Metric_Pad1.20x1.40mm_HandSolder; not fitted
R26: 1k; R_0805_2012Metric_Pad1.20x1.40mm_HandSolder
R27: 100Ω; R_0805_2012Metric_Pad1.20x1.40mm_HandSolder
R29: 10k; R_0805_2012Metric_Pad1.20x1.40mm_HandSolder
U1, U2: SN74LVC4245ADWR; DW24-M
U3: SN74LVC14ADR; D14-M
U4: AM26LV32EIDR; D16-M
U5: SN74LVC1T45DBVR; DBV0006A_M

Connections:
+3V3: A1.36 (3V3), C2.2, C4.2, C5.2, C6.2, C8.2, C10.1, R29.1, U1.23 (VCCB), U1.24 (VCCB), U2.23 (VCCB), U2.24 (VCCB), U3.14 (VCC), U4.4 (G), U4.10 (3A), U4.14 (4A), U4.16 (VCC), U5.6 (VCCB)
+5V: A1.40 (VBUS), C1.2, C3.2, C7.2, C9.1, JP1.2, R17.1, R18.2, R19.2, U1.1 (VCCA), U2.1 (VCCA), U5.1 (VCCA)
/+READ_DATA: J1.48 (+READ_DATA), R27.2, U4.6 (2A)
/+READ_REF_CLK: J1.45 (+READ/REF_CLK), R26.2, U4.2 (1A)
/-READ_DATA: J1.49 (-READ_DATA), R27.1, U4.7 (2B)
/-READ_REF_CLK: J1.46 (-READ/REF_CLK), R26.1, U4.1 (1B)
/AD0: J1.20 (AD0), R13.1
/AD0_3V3: A1.12 (GPIO9), U2.17 (B5)
/AD1: J1.19 (AD1), R12.1
/AD1_3V3: A1.14 (GPIO10), U2.18 (B4)
/DBUS0: J1.2 (DBUS0), R1.1
/DBUS0_3V3: A1.1 (GPIO0), U1.21 (B1)
/DBUS1: J1.3 (DBUS1), R2.1
/DBUS1_3V3: A1.2 (GPIO1), U1.20 (B2)
/DBUS2: J1.4 (DBUS2), R3.1
/DBUS2_3V3: A1.4 (GPIO2), U1.19 (B3)
/DBUS3: J1.5 (DBUS3), R4.1
/DBUS3_3V3: A1.5 (GPIO3), U1.18 (B4)
/DBUS4: J1.6 (DBUS4), R5.1
/DBUS4_3V3: A1.6 (GPIO4), U1.17 (B5)
/DBUS5: J1.7 (DBUS5), R6.1
/DBUS5_3V3: A1.7 (GPIO5), U1.16 (B6)
/DBUS6: J1.8 (DBUS6), R7.1
/DBUS6_3V3: A1.9 (GPIO6), U1.15 (B7)
/DBUS7: J1.9 (DBUS7), R8.1
/DBUS7_3V3: A1.10 (GPIO7), U1.14 (B8)
/DBUS_DIR_3V3: A1.11 (GPIO8), U1.2 (DIR)
/INDEX: A1.24 (GPIO18), U3.2 (1Y)
/READY: A1.25 (GPIO19), U3.4 (2Y)
/READ_DATA: A1.29 (GPIO22), U4.5 (2Y)
/READ_REF_CLK: A1.27 (GPIO21), U4.3 (1Y)
/SECTOR_MARK: A1.26 (GPIO20), U3.6 (3Y)
/TERMINATION_POWER: J1.28 (+5V_TERM), JP1.1
/~HEAD_SELECT_1: J1.31 (~HEAD_SELECT_1), R16.1
/~HEAD_SELECT_1_3V3: A1.17 (GPIO13), U2.14 (B8)
/~HEAD_SELECT_2: J1.30 (~HEAD_SELECT_2), R15.1
/~HEAD_SELECT_2_3V3: A1.19 (GPIO14), U2.15 (B7)
/~HEAD_SELECT_4: J1.29 (~HEAD_SELECT_4), R14.1
/~HEAD_SELECT_4_3V3: A1.20 (GPIO15), U2.16 (B6)
/~INDEX: J1.33 (~INDEX), R17.2, R20.2, U3.1 (1A)
/~RD: J1.17 (~RD), R10.1
/~RD_3V3: A1.15 (GPIO11), U2.20 (B2)
/~READY: J1.35 (~READY), R18.1, R21.1, U3.3 (2A)
/~READ_GATE: J1.11 (~READ_GATE), R9.1
/~READ_GATE_3V3: A1.21 (GPIO16), U2.21 (B1)
/~RESET: J1.13 (~RESET), R28.2
/~RESET_3V3: A1.22 (GPIO17), R29.2, U5.4 (B)
/~SECTOR_MARK: J1.37 (~SECTOR_MARK), R19.1, R22.1, U3.5 (3A)
/~WR: J1.18 (~WR), R11.1
/~WR_3V3: A1.16 (GPIO12), U2.19 (B3)
GND: A1.3 (GND), A1.8 (GND), A1.13 (GND), A1.18 (GND), A1.23 (GND), A1.28 (GND), A1.33 (AGND), A1.38 (GND), C1.1, C2.1, C3.1, C4.1, C5.1, C6.1, C7.1, C8.1, C9.2, C10.2, H1.1 (1_1), H2.1 (1_1), H3.1 (1_1), H4.1 (1_1), J1.1 (GND), J1.10 (GND), J1.12 (GND), J1.14 (GND), J1.16 (GND), J1.21 (GND), J1.22 (~DRIVE_SELECT_1), J1.26 (GND), J1.27 (GND), J1.32 (GND), J1.34 (GND), J1.36 (GND), J1.38 (GND), J1.41 (GND), J1.44 (GND), J1.47 (GND), J1.50 (GND), R20.1, R21.2, R22.2, U1.11 (GND), U1.12 (GND), U1.13 (GND), U1.22 (*OE), U2.2 (DIR), U2.11 (GND), U2.12 (GND), U2.13 (GND), U2.22 (*OE), U3.7 (GND), U3.9 (4A), U3.11 (5A), U3.13 (6A), U4.8 (GND), U4.9 (3B), U4.12 (*G), U4.15 (4B), U5.2 (GND), U5.5 (DIR)
unnamed: R1.2, U1.3 (A1)
unnamed: R2.2, U1.4 (A2)
unnamed: R3.2, U1.5 (A3)
unnamed: R4.2, U1.6 (A4)
unnamed: R5.2, U1.7 (A5)
unnamed: R6.2, U1.8 (A6)
unnamed: R7.2, U1.9 (A7)
unnamed: R8.2, U1.10 (A8)
unnamed: R9.2, U2.3 (A1)
unnamed: R10.2, U2.4 (A2)
unnamed: R11.2, U2.5 (A3)
unnamed: R12.2, U2.6 (A4)
unnamed: R13.2, U2.7 (A5)
unnamed: R14.2, U2.8 (A6)
unnamed: R15.2, U2.9 (A7)
unnamed: R16.2, U2.10 (A8)
unnamed: R28.1, U5.3 (A)

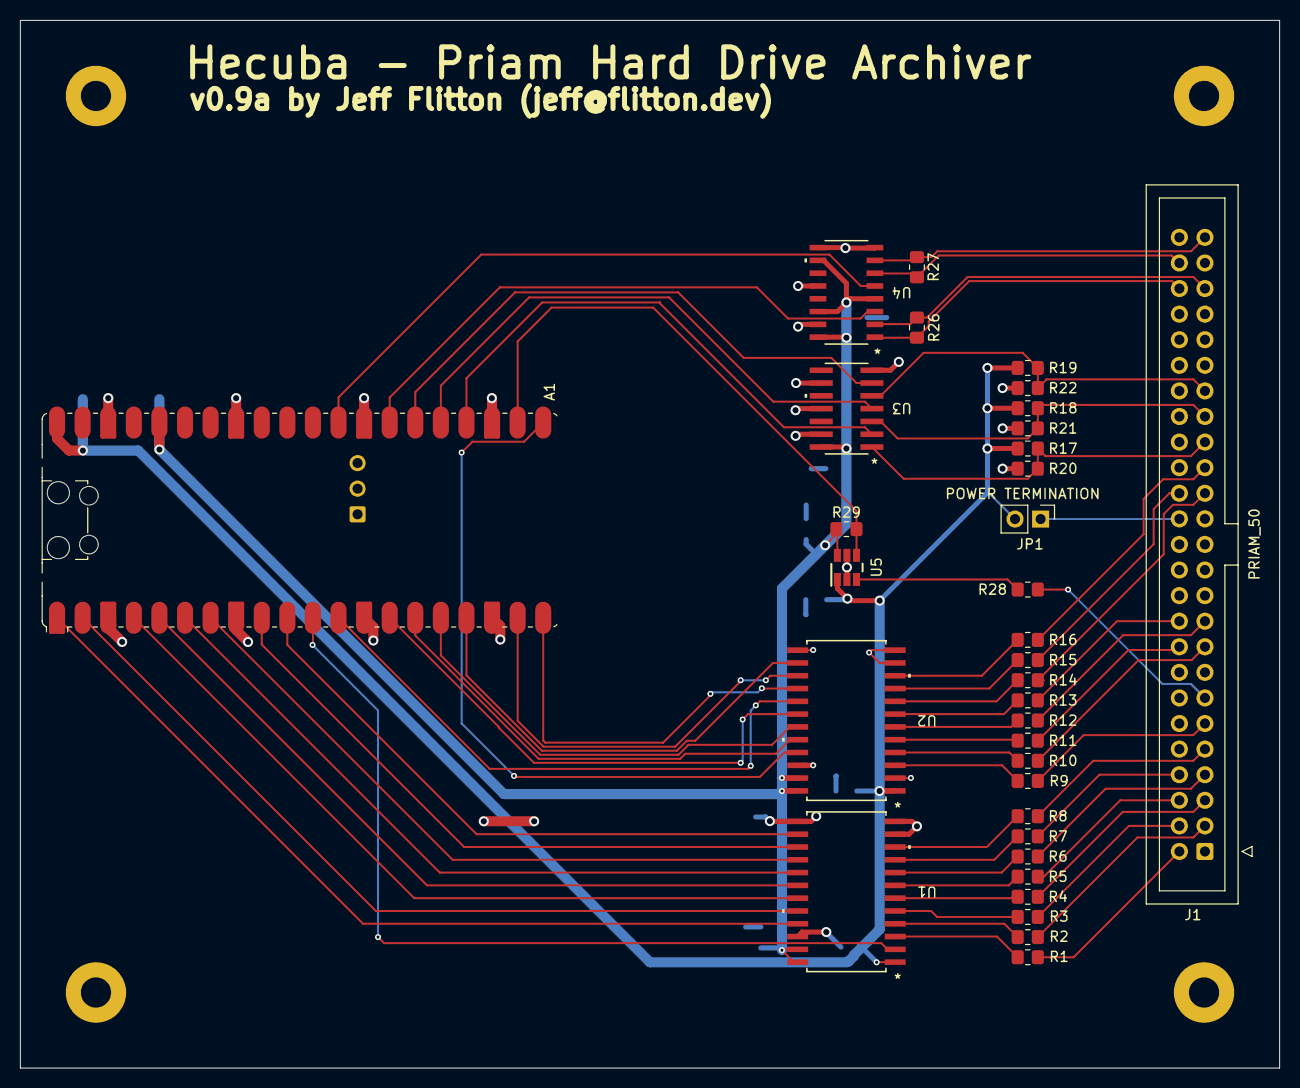
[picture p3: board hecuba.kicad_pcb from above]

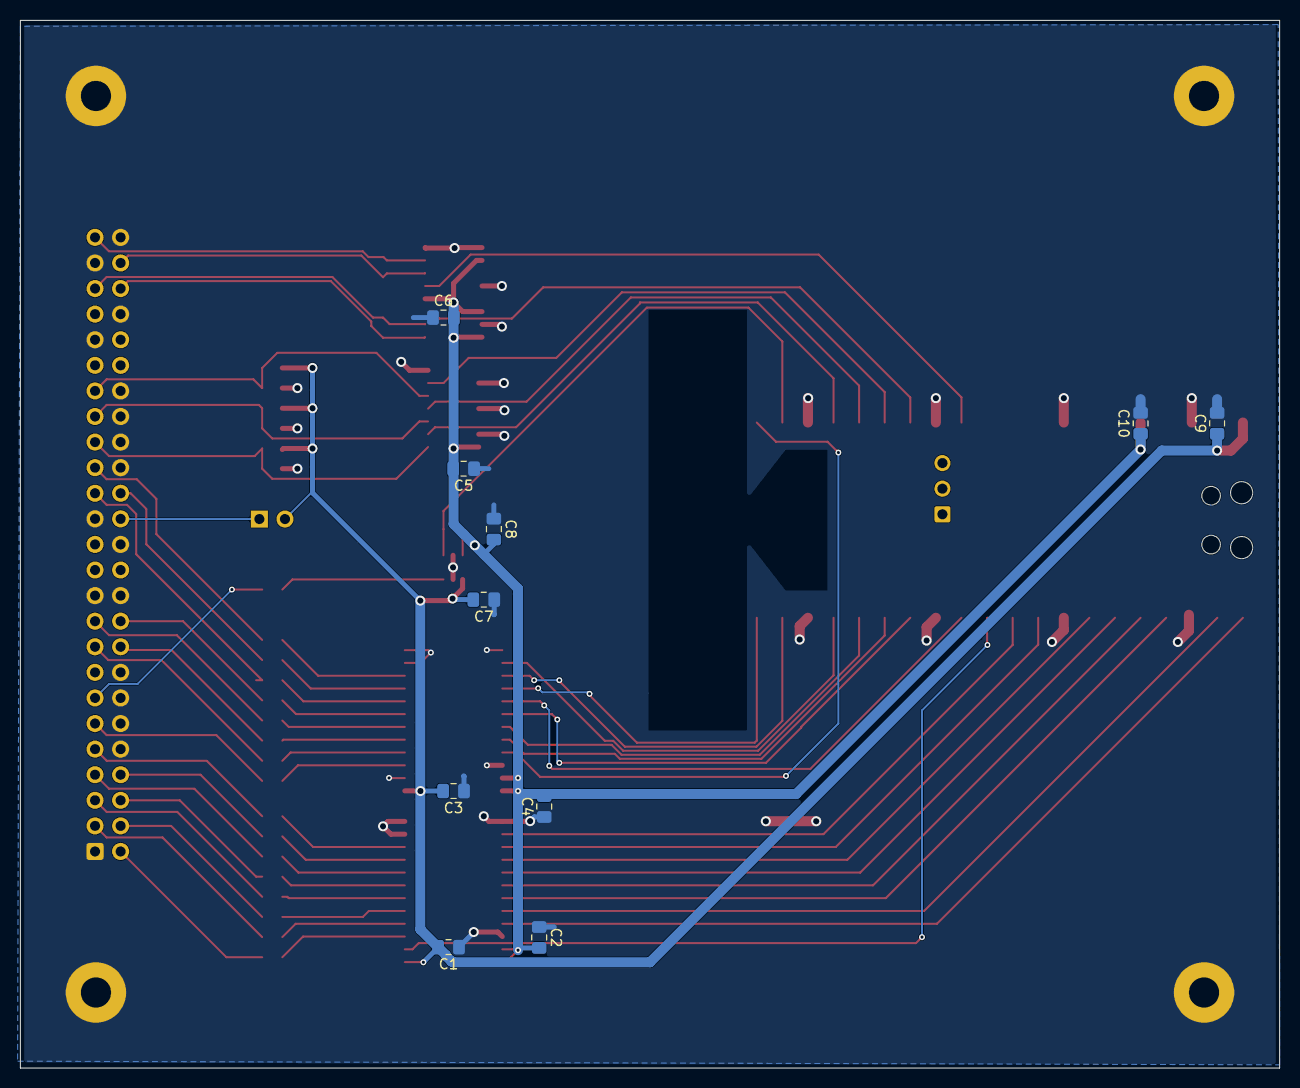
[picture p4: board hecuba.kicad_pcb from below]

Board: 2 copper layers, 125.0 x 104.0 mm, 48 parts (10 on the bottom side), 68 nets.

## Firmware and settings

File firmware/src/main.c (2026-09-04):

// main.c - Hecuba acquisition controller entry point.
//
// Core split (CORE-4):
//   * core1: PIO+DMA whole-track capture engine (capture.c), launched lazily
//             on the first `capture` so the console never waits on it
//   * core0: register-bus protocol + USB-CDC host console (this file)
//
// SAFETY (SAF-2): there is no firmware path that asserts -WRITE GATE or drives
// the WRITE DATA/CLOCK lines. -WRITE GATE is held deasserted in hardware and
// those nets are not even wired to the core.

#include <stdio.h>
#include "pico/stdlib.h"
#include "pico/stdio_usb.h"
#include "pico/cyw43_arch.h"

#include "priam_bus.h"
#include "host_cli.h"

// Onboard-LED heartbeat: 1 Hz = firmware alive. The LED sits on the CYW43
// radio (no RP2350 GPIO), hence cyw43_arch. It freezes during a capture
// (core0 blocks on core1); that stall is itself a useful bench signal.
#define HEARTBEAT_HALF_PERIOD_MS 500u

int main(void) {
    // Park the drive-facing lines before anything else. From power-on until
    // this call the RP2350 pad pull-downs hold U2's inputs low, i.e. the
    // active-low strobes sit asserted at the drive, so keep that window minimal
    // (and see README: power the Pico before the drive rails).
    priam_bus_init();

    stdio_init_all();          // USB-CDC console (CMake: stdio_usb on, uart off)

    bool led_ok = (cyw43_arch_init() == 0);   // LED lives on the CYW43

    // The capture engine (core1) is started lazily on the first `capture`
    // command (see capture_run_blocking), so the console + register bus come up
    // unconditionally; reading Status never depends on PIO/DMA bring-up.
    host_cli_init();

    bool connected = false;
    bool led_on = false;
    absolute_time_t next_beat = get_absolute_time();

    for (;;) {
        // Print the banner on each (re)connect rather than at boot: bytes
        // written before a terminal attaches are dropped by the USB stack.
        bool now_connected = stdio_usb_connected();
        if (now_connected && !connected) {
            sleep_ms(25);      // let the host finish opening the port
            printf("\n=== Hecuba PRIAM acquisition controller (RP2350 / Pico 2 W) ===\n");
            printf("read-only: no write path in firmware. type 'help'.\n");
            if (!led_ok) printf("(cyw43_arch_init failed: no LED heartbeat)\n");
            printf("> ");
        }
        connected = now_connected;

        if (led_ok && time_reached(next_beat)) {
            led_on = !led_on;
            cyw43_arch_gpio_put(CYW43_WL_GPIO_LED_PIN, led_on);
            next_beat = make_timeout_time_ms(HEARTBEAT_HALF_PERIOD_MS);
        }

        host_cli_task();
        tight_loop_contents();
    }
}

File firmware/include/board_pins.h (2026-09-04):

// board_pins.h - Hecuba controller GPIO map (RP2350 / Pico 2 W, ref A1)
//
// SINGLE SOURCE OF TRUTH for pin assignments, transcribed from the KiCad
// schematic in ../hardware. If the schematic changes, update this file to
// match it.
//
// ============================ POLARITY / SIGNAL CHAIN =======================
// Every line between the core and the 5 V drive is voltage-translated:
//
//   * DBUS0..7      U1  SN74LVC4245A  bidirectional, non-inverting.
//                       DIR = GP8 (PIN_DBUS_DIR): 0 => B->A (core drives = WRITE),
//                       1 => A->B (drive drives = READ). OE tied low (always on).
//   * Control outs  U2  SN74LVC4245A  DIR strapped low => always B->A,
//                       non-inverting. So a core GPIO level passes straight to the
//                       drive line. These drive lines are ACTIVE-LOW, therefore:
//                       assert  => drive GPIO LOW,  deassert => drive GPIO HIGH.
//                       (AD0/AD1 are plain logic levels, not active-low strobes.)
//   * -RESET        U5  SN74LVC1T45   DIR low => B->A, non-inverting. Active-low:
//                       GPIO LOW = reset asserted. R29 10k pulls GP17 high so the
//                       drive sees -RESET deasserted through boot (GP17 resets to
//                       input). Firmware drives GP17 output HIGH early to hold it.
//   * Status ins    U3  SN74LVC14A    INVERTING Schmitt. The drive's active-low
//                       -INDEX/-READY/-SECTOR MARK arrive at the core ACTIVE-HIGH:
//                       gpio_get(pin) == 1  means the signal is ASSERTED.
//   * READ DATA /   U4  AM26LV32E      RS-422 receiver, non-inverting -> clean
//     READ/REF CLK                     3V3 logic at the core.
//
// There is no -DRIVE SELECT GPIO: it is hard-tied asserted on the board for the
// single-drive setup (SIG-5), so firmware never drives a chip select.
// ============================================================================

#ifndef HECUBA_BOARD_PINS_H
#define HECUBA_BOARD_PINS_H

// ----- DBUS 0..7 : contiguous on GP0..GP7 (one byte, mask-addressable) ------
#define PIN_DBUS_BASE      0u
#define PIN_DBUS0          0u
#define PIN_DBUS7          7u
#define DBUS_MASK          (0xFFu << PIN_DBUS_BASE)   // 0x000000FF

// ----- Control / address outputs (via U2, non-inverting, active-low) --------
#define PIN_DBUS_DIR       8u    // U1 direction: 0=write(B->A), 1=read(A->B)
#define PIN_AD0            9u    // register select A0 (logic level)
#define PIN_AD1           10u    // register select A1 (logic level)
#define PIN_RD_N          11u    // -RD  strobe (assert = LOW)
#define PIN_WR_N          12u    // -WR  strobe (assert = LOW)
#define PIN_HS1_N         13u    // -HEAD SELECT 1 (assert = LOW)
#define PIN_HS2_N         14u    // -HEAD SELECT 2 (assert = LOW)
#define PIN_HS4_N         15u    // -HEAD SELECT 4 (assert = LOW)
#define PIN_READ_GATE_N   16u    // -READ GATE (assert = LOW)
#define PIN_RESET_N       17u    // -RESET via U5 (assert = LOW); R29 holds high

// ----- Status inputs (via U3, INVERTING -> active-HIGH at the core) ---------
#define PIN_INDEX         18u    // -INDEX       : core HIGH = index pulse
#define PIN_READY         19u    // -READY       : core HIGH = drive ready
#define PIN_SECTOR_MARK   20u    // -SECTOR MARK : core HIGH = sector mark

// ----- High-speed serial capture inputs (via U4 RS-422 rx) ------------------
#define PIN_READ_REF_CLK  21u    // recovered bit clock  (PIO `wait gpio`)
#define PIN_READ_DATA     22u    // recovered NRZ data   (PIO `in pins`)

// Aggregate masks for batch GPIO init.
#define CONTROL_OUT_MASK ( (1u<<PIN_DBUS_DIR) | (1u<<PIN_AD0) | (1u<<PIN_AD1) | \
                           (1u<<PIN_RD_N) | (1u<<PIN_WR_N) | \
                           (1u<<PIN_HS1_N) | (1u<<PIN_HS2_N) | (1u<<PIN_HS4_N) | \
                           (1u<<PIN_READ_GATE_N) | (1u<<PIN_RESET_N) )

#define STATUS_IN_MASK   ( (1u<<PIN_INDEX) | (1u<<PIN_READY) | (1u<<PIN_SECTOR_MARK) )

// Active-low control lines whose idle (deasserted) state is HIGH. -RESET is
// included so init parks it deasserted; DBUS_DIR/AD0/AD1 are excluded (they are
// logic levels, not active-low strobes; they default to a benign 0).
#define CONTROL_IDLE_HIGH_MASK ( (1u<<PIN_RD_N) | (1u<<PIN_WR_N) | \
                                 (1u<<PIN_HS1_N) | (1u<<PIN_HS2_N) | (1u<<PIN_HS4_N) | \
                                 (1u<<PIN_READ_GATE_N) | (1u<<PIN_RESET_N) )

#endif // HECUBA_BOARD_PINS_H

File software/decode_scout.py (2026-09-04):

#!/usr/bin/env python3
"""decode_scout.py - iSBC 215 sector decoder for hecuba whole-track NRZ captures.

Reads `dumpb64` capture blocks out of a screen log (or raw .bin track files),
finds iSBC 215 sector structure at any bit alignment, ECC-checks every field,
and merges results across captures: a sector is recovered once its data ECC
validates in ANY read.

FORMAT (verified against real Priam 3450 captures; differs from Gesswein's
trk_ISBC215_512B in two ways: no A1 bytes on the Priam-native NRZ interface,
and data sync is 0x19, not 0xD9, per the iSBC 215 manual's "sync byte is
always 19H except Shugart/Quantum" note):

  header: 00-preamble | 19 | flags+size 20 | cyl-lo | sector | head | ECC32
  data:   00-preamble | 19 | 512 data bytes | ECC32          (write splice
          between the fields => independent bit alignment)

  ECC: CRC-32, poly 0x00A00805 (x^32+...; 11-bit burst correcting), MSB-first,
  non-reflected, computed over sync byte + field bytes, init 0. The controller's
  init/complement conventions fold into per-field constants:
      crc(field_bytes, init=0) XOR stored_ecc == K
  K_HDR  = 0xD9FFFEFD   (validated 20/20 distinct sectors)
  K_DATA = 0xE33E6F19   (validated on ECC-consistent data sectors)

Geometry: 23 sectors/track (hard-sectored, interleave 1), 512 B/sector,
cylinder in header low-nibble<<8 | cyl-lo, track = 13,440 bytes, ~107,523 bits.
"""
import argparse
import base64
import re
import sys
from collections import Counter

B64_BLOCK = re.compile(
    r'-----BEGIN CAPTURE b64 \((\d+) words.*?-----\r?\n(.*?)-----END CAPTURE-----',
    re.S)

POLY = 0x00A00805
K_HDR = 0xD9FFFEFD
K_DATA = 0xE33E6F19
SYNC = 0x19
SECTOR_SIZE = 512
SECTORS_PER_TRACK = 23
DATA_SEARCH_BITS = 700       # window after header end to hunt the data sync
PREAMBLE_BITS = 16           # zero bits required before a data sync candidate


def crc32p(data: bytes, init: int = 0) -> int:
    crc = init
    for b in data:
        crc ^= b << 24
        for _ in range(8):
            crc = ((crc << 1) ^ POLY) if (crc & 0x80000000) else (crc << 1)
            crc &= 0xFFFFFFFF
    return crc


# ---- burst-error correction (error trapping) --------------------------------
# The code corrects short bursts: syndrome s = crc(received field+ecc) ^ const.
# An error burst b(x)*x^j has syndrome b(x)*x^j mod p, so stepping the syndrome
# by x^-1 walks j down; when the register fits in MAX_BURST bits, the burst is
# trapped at offset j from the codeword end. Span limited to 4 bits, the same
# limit Gesswein uses for this polynomial to avoid miscorrection.
MAX_BURST = 4


def correct_burst(field: bytes, stored: int, k_const: int):
    """Return corrected field bytes, or None. field excludes the stored ECC."""
    syn = crc32p(field) ^ stored ^ k_const
    if syn == 0:
        return field
    # full codeword = field bits + 32 ecc bits
    n = len(field) * 8 + 32
    p_full = (1 << 32) | POLY
    t = syn
    for j in range(n):
        if t and t < (1 << MAX_BURST):
            # burst pattern t ends j bits from the codeword end
            if j < 32:
                return None       # burst inside the ECC bytes: field is fine
            e_bit_from_end = j    # LSB of t sits j bits from end
            fixed = bytearray(field)
            for bi in range(MAX_BURST):
                if t & (1 << bi):
                    pos_from_end = e_bit_from_end + bi
                    bit_index = n - 32 - 1 - (pos_from_end - 32)
                    if not (0 <= bit_index < len(field) * 8):
                        return None
                    fixed[bit_index >> 3] ^= 0x80 >> (bit_index & 7)
            fixed = bytes(fixed)
            if (crc32p(fixed) ^ stored ^ k_const) == 0:
                return fixed
            return None
        # t *= x^-1 mod p  (p monic degree 32, constant term 1)
        if t & 1:
            t ^= p_full
        t >>= 1
    return None


def load_captures(path):
    data = open(path, 'rb').read()
    if path.endswith('.bin'):
        return [data]
    text = data.decode('utf-8', 'replace')
    return [base64.b64decode(''.join(b.split()))
            for _, b in B64_BLOCK.findall(text)]


def words_to_bits(raw: bytes) -> list:
    """LE 32-bit words -> bit list; bit 0 of word 0 = first bit after INDEX."""
    bits = []
    for i in range(0, len(raw), 4):
        w = int.from_bytes(raw[i:i + 4], 'little')
        bits.extend((w >> k) & 1 for k in range(32))
    return bits


def bits_to_byte(bits, pos):
    v = 0
    for k in range(8):
        v = (v << 1) | bits[pos + k]
    return v


def read_bytes(bits, pos, n):
    if pos < 0 or pos + 8 * n > len(bits):
        return None
    return bytes(bits_to_byte(bits, pos + 8 * k) for k in range(n))


def find_marks(bits, run=40):
    """positions of 1-bits ending zero runs (legacy helper)."""
    marks, r = [], 0
    for i, b in enumerate(bits):
        if b == 0:
            r += 1
        else:
            if r >= run:
                marks.append(i)
            r = 0
    return marks


def bit_views(bits):
    """8 byte-aligned views of the bitstream, one per bit offset."""
    out = []
    for off in range(8):
        ba = bytearray()
        v = cnt = 0
        for i in range(off, len(bits)):
            v = (v << 1) | bits[i]
            cnt += 1
            if cnt == 8:
                ba.append(v)
                v = cnt = 0
        out.append(bytes(ba))
    return out


def find_headers(bits):
    """All ECC-valid headers: (bitpos, cyl, head, sector).
    Flags byte is 0x20 | cyl[10:8], so match 0x20-0x27 (cyl up to 524 needs
    0x20/0x21/0x22)."""
    out = []
    for off, view in enumerate(bit_views(bits)):
        start = 0
        while True:
            idx = view.find(bytes([SYNC]), start)
            if idx < 0:
                break
            start = idx + 1
            w = view[idx:idx + 9]
            if len(w) < 9 or (w[1] & 0xF8) != 0x20:
                continue
            if (crc32p(w[:5]) ^ int.from_bytes(w[5:9], 'big')) != K_HDR:
                continue
            cyl = ((w[1] & 0x0F) << 8) | w[2]
            out.append((off + idx * 8, cyl, w[4], w[3]))
    return sorted(out)
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

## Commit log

2026-09-04 Hecuba: read-only imager for Priam DISKOS 8-inch drives
    Interface board (KiCad), Raspberry Pi Pico 2 W firmware, and host tools
    for whole-drive imaging, offline sector recovery, and iRMX-86 filesystem
    walking. Built to recover a Priam 3450 from an Intel Multibus system.
    [bom.csv, hecuba.kicad_pcb, hecuba.kicad_sch]
2026-09-12 Drive reset doesn't end in fault, that's just a brief, transient state
    [host_cli.c]
